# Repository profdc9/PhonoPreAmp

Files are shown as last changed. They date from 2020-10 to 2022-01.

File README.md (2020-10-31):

# Phono Preamplifier

This is a PCB for Bill Christie's phono preamplifier as detailed in his article "Build an External Phonograph Preamplifier" in the 07/13 issue of audioXpress.  The original article can be found at

https://audioxpress.com/article/You-Can-DIY-Build-an-External-Phono-Preamplifier

https://audioxpress.com/assets/upload/files/BillChristieExternalPhonoPreampAXJul2013.pdf

The changes made are as follows.  The LME49740, which is not available anymore, has been replaced with two LM4562 op amps.  22 pF Miller capacitors are placed to stabilize the LM4562 from oscillation.  The signal grounds for the two channels are isolated from the power ground by hum breaker resistors.

This is a two-channel PCB layout for the LM3886-based Super Gain Clone by Bob Cordell.  It can be found in Chapter 27 in his book "Audio Amplifiers."

The PCB is made available under the Creative Commons CC-BY-SA 4.0 license.

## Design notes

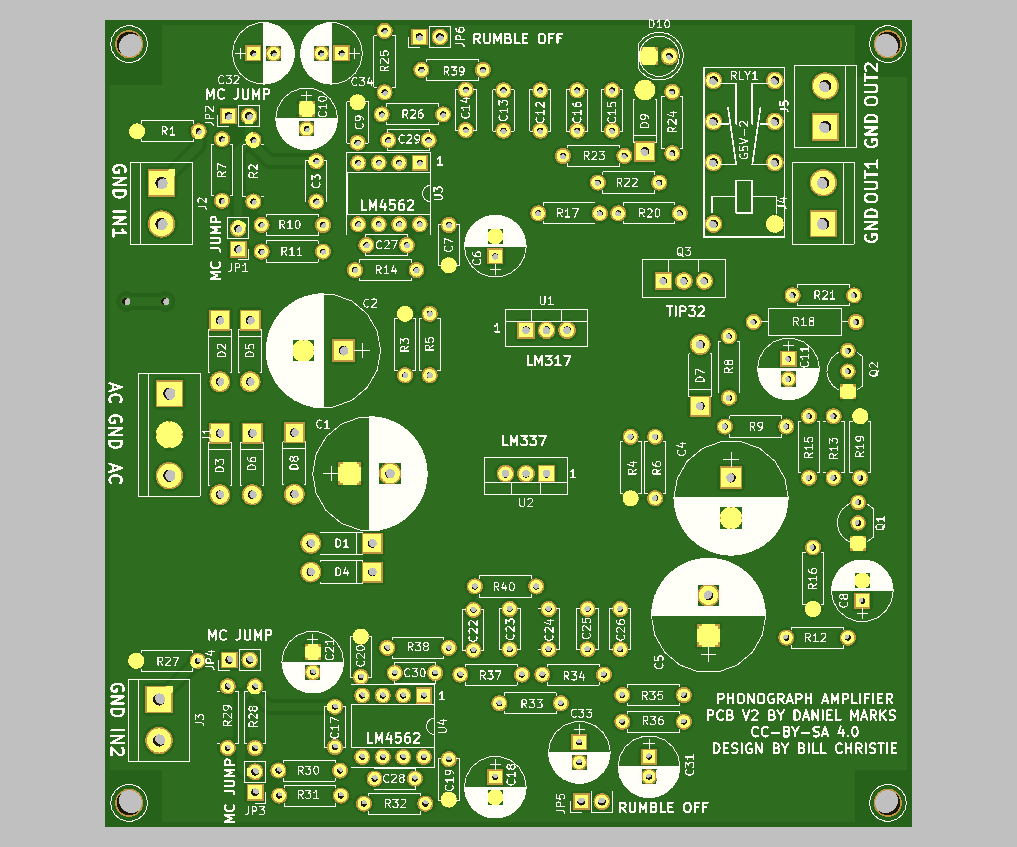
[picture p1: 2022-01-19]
PhonoPreamp.png

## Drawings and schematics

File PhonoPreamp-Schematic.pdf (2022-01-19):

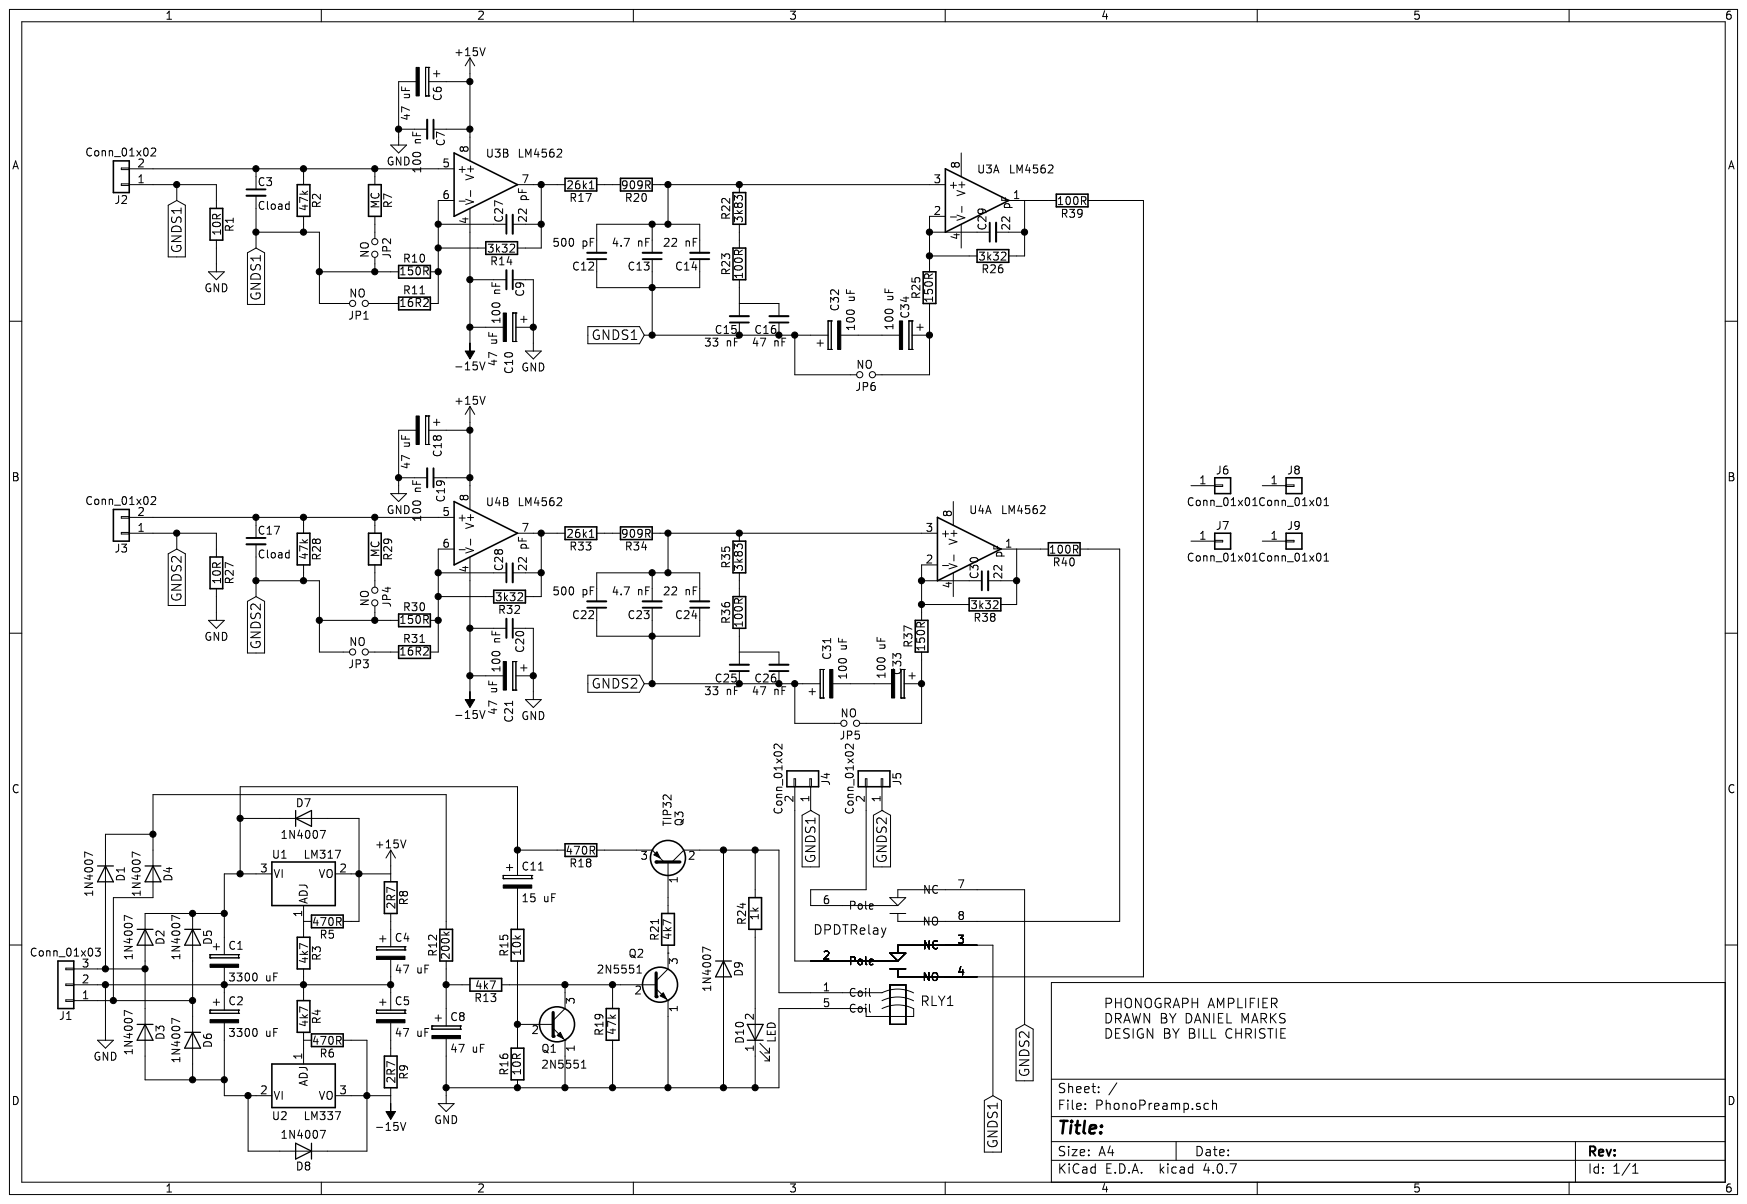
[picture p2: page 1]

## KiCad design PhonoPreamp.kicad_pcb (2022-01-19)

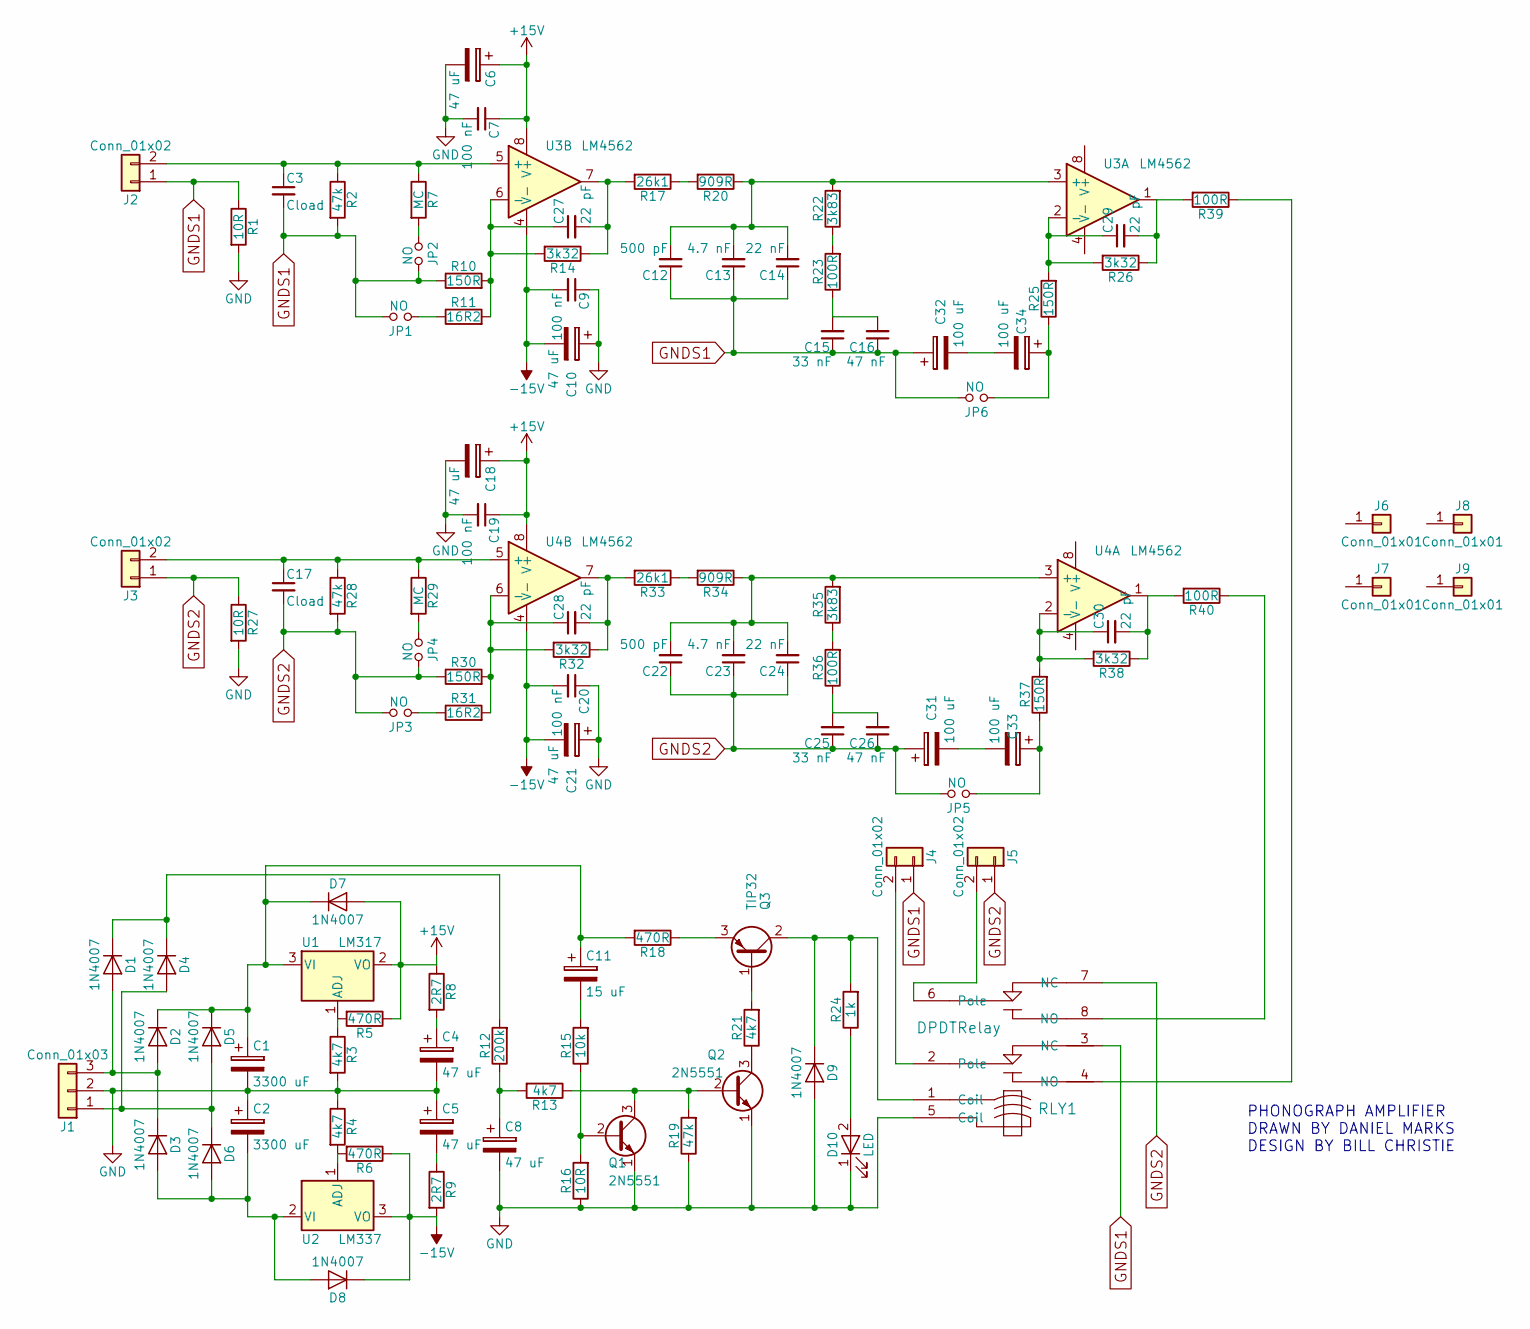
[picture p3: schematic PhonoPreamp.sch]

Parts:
C1, C2: 3300 uF; CP_Radial_D14.0mm_P5.00mm
C3, C17: Cload; C_Disc_D5.0mm_W2.5mm_P5.00mm
C4, C5: 47 uF; CP_Radial_D14.0mm_P5.00mm
C6, C8, C10, C18, C21: 47 uF; CP_Radial_D7.5mm_P2.50mm
C7, C9, C19, C20: 100 nF; C_Disc_D5.0mm_W2.5mm_P5.00mm
C11: 15 uF; CP_Radial_D7.5mm_P2.50mm
C12, C22: 500 pF; C_Disc_D5.0mm_W2.5mm_P5.00mm
C13, C23: 4.7 nF; C_Disc_D5.0mm_W2.5mm_P5.00mm
C14, C24: 22 nF; C_Disc_D5.0mm_W2.5mm_P5.00mm
C15, C25: 33 nF; C_Disc_D5.0mm_W2.5mm_P5.00mm
C16, C26: 47 nF; C_Disc_D5.0mm_W2.5mm_P5.00mm
C27, C28, C29, C30: 22 pF; C_Disc_D5.0mm_W2.5mm_P5.00mm
C31, C32, C33, C34: 100 uF; CP_Radial_D7.5mm_P2.50mm
D1, D2, D3, D4, D5, D6, D7, D8, D9: 1N4007; D_DO-41_SOD81_P7.62mm_Horizontal
D10: LED; LED_D5.0mm
J1: Conn_01x03; TerminalBlock_bornier-3_P5.08mm
J2, J3, J4, J5: Conn_01x02; TerminalBlock_bornier-2_P5.08mm
J6, J7, J8, J9: Conn_01x01; 1pin
JP1, JP2, JP3, JP4, JP5, JP6: NO; Pin_Header_Straight_1x02_Pitch2.54mm
Q1, Q2: 2N5551; TO-92_Inline_Wide
Q3: TIP32; TO-220-3_Vertical
R1, R16, R27: 10R; R_Axial_DIN0207_L6.3mm_D2.5mm_P7.62mm_Horizontal
R2, R19, R28: 47k; R_Axial_DIN0207_L6.3mm_D2.5mm_P7.62mm_Horizontal
R3, R4, R13, R21: 4k7; R_Axial_DIN0207_L6.3mm_D2.5mm_P7.62mm_Horizontal
R5, R6: 470R; R_Axial_DIN0207_L6.3mm_D2.5mm_P7.62mm_Horizontal
R7, R29: MC; R_Axial_DIN0207_L6.3mm_D2.5mm_P7.62mm_Horizontal
R8, R9: 2R7; R_Axial_DIN0207_L6.3mm_D2.5mm_P7.62mm_Horizontal
R10, R25, R30, R37: 150R; R_Axial_DIN0207_L6.3mm_D2.5mm_P7.62mm_Horizontal
R11, R31: 16R2; R_Axial_DIN0207_L6.3mm_D2.5mm_P7.62mm_Horizontal
R12: 200k; R_Axial_DIN0207_L6.3mm_D2.5mm_P7.62mm_Horizontal
R14, R26, R32, R38: 3k32; R_Axial_DIN0207_L6.3mm_D2.5mm_P7.62mm_Horizontal
R15: 10k; R_Axial_DIN0207_L6.3mm_D2.5mm_P7.62mm_Horizontal
R17, R33: 26k1; R_Axial_DIN0207_L6.3mm_D2.5mm_P7.62mm_Horizontal
R18: 470R; R_Axial_DIN0309_L9.0mm_D3.2mm_P12.70mm_Horizontal
R20, R34: 909R; R_Axial_DIN0207_L6.3mm_D2.5mm_P7.62mm_Horizontal
R22, R35: 3k83; R_Axial_DIN0207_L6.3mm_D2.5mm_P7.62mm_Horizontal
R23, R36, R39, R40: 100R; R_Axial_DIN0207_L6.3mm_D2.5mm_P7.62mm_Horizontal
R24: 1k; R_Axial_DIN0207_L6.3mm_D2.5mm_P7.62mm_Horizontal
RLY1: DPDTRelay; G2VRelay
U1: LM317; TO-220-3_Vertical
U2: LM337; TO-220-3_Vertical
U3, U4: LM4562; DIP-8_W7.62mm_Socket

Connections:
+15V: C6.1, C7.1, C18.1, C19.1, D7.2 (A), R5.1, R8.1, U1.2 (VO), U3.8 (V+), U4.8 (V+)
-15V: C9.2, C10.2, C20.2, C21.2, D8.1 (K), R6.1, R9.2, U2.3 (VO), U3.4 (V-), U4.4 (V-)
GND: C1.2, C2.1, C4.2, C5.1, C6.2, C7.2, C8.2, C9.1, C10.1, C18.2, C19.2, C20.1, C21.1, D9.2 (A), D10.1 (K), J1.2, Q1.1 (E), Q2.1 (E), R1.2, R3.2, R4.1, R16.1, R19.1, R27.2, RLY1.5 (Coil)
GNDS1: C3.2, C12.1, C13.1, C14.1, C15.1, C16.1, C32.1, J2.1, J4.1, JP1.2, JP2.2, JP6.2, R1.1, R2.2, R10.1, RLY1.3 (NC)
GNDS2: C17.2, C22.1, C23.1, C24.1, C25.1, C26.1, C31.1, J3.1, J5.1, JP3.2, JP4.2, JP5.2, R27.1, R28.2, R30.1, RLY1.7 (NC)
unnamed: C1.1, C11.1, D2.1 (K), D5.1 (K), D7.1 (K), R18.2, U1.3 (VI)
unnamed: C2.2, D3.2 (A), D6.2 (A), D8.2 (A), U2.2 (VI)
unnamed: C3.1, J2.2, R2.1, R7.1, U3.5 (+)
unnamed: C4.1, R8.2
unnamed: C5.2, R9.1
unnamed: C8.1, R12.1, R13.2
unnamed: C11.2, R15.2
unnamed: C12.2, C13.2, C14.2, R20.1, R22.2, U3.3 (+)
unnamed: C15.2, C16.2, R23.1
unnamed: C17.1, J3.2, R28.1, R29.1, U4.5 (+)
unnamed: C22.2, C23.2, C24.2, R34.1, R35.2, U4.3 (+)
unnamed: C25.2, C26.2, R36.1
unnamed: C27.1, R10.2, R11.2, R14.2, U3.6 (-)
unnamed: C27.2, R14.1, R17.2, U3.7
unnamed: C28.1, R30.2, R31.2, R32.2, U4.6 (-)
unnamed: C28.2, R32.1, R33.2, U4.7
unnamed: C29.1, R25.2, R26.2, U3.2 (-)
unnamed: C29.2, R26.1, R39.2, U3.1
unnamed: C30.1, R37.2, R38.2, U4.2 (-)
unnamed: C30.2, R38.1, R40.2, U4.1
unnamed: C31.2, C33.2
unnamed: C32.2, C34.2
unnamed: C33.1, JP5.1, R37.1
unnamed: C34.1, JP6.1, R25.1
unnamed: D1.1 (K), D4.1 (K), R12.2
unnamed: D1.2 (A), D2.2 (A), D3.1 (K), J1.3
unnamed: D4.2 (A), D5.2 (A), D6.1 (K), J1.1
unnamed: D9.1 (K), Q3.2 (C), R24.2, RLY1.1 (Coil)
unnamed: D10.2 (A), R24.1
unnamed: J4.2, RLY1.2 (Pole)
unnamed: J5.2, RLY1.6 (Pole)
unnamed: JP1.1, R11.1
unnamed: JP2.1, R7.2
unnamed: JP3.1, R31.1
unnamed: JP4.1, R29.2
unnamed: Q1.2 (B), R15.1, R16.2
unnamed: Q1.3 (C), Q2.2 (B), R13.1, R19.2
unnamed: Q2.3 (C), R21.1
unnamed: Q3.1 (B), R21.2
unnamed: Q3.3 (E), R18.1
unnamed: R3.1, R5.2, U1.1 (ADJ)
unnamed: R4.2, R6.2, U2.1 (ADJ)
unnamed: R17.1, R20.2
unnamed: R22.1, R23.2
unnamed: R33.1, R34.2
unnamed: R35.1, R36.2
unnamed: R39.1, RLY1.4 (NO)
unnamed: R40.1, RLY1.8 (NO)

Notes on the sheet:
PHONOGRAPH AMPLIFIER DRAWN BY DANIEL MARKS DESIGN BY BILL CHRISTIE

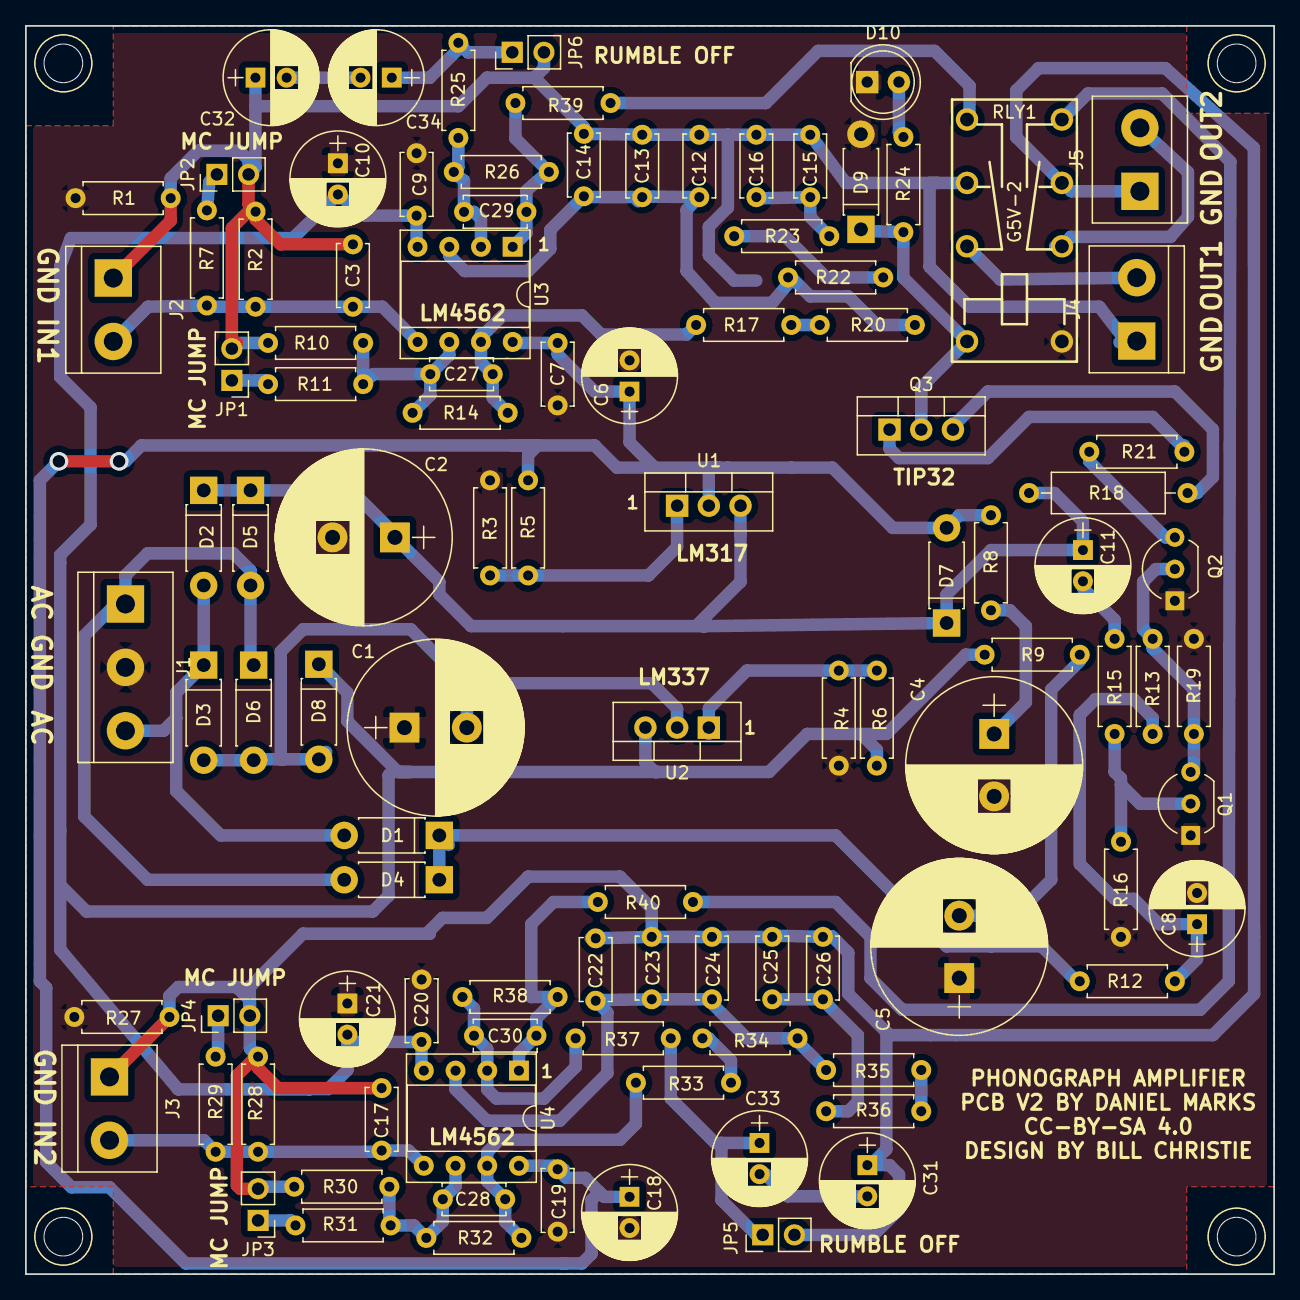
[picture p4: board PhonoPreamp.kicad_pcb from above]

Board: 2 copper layers, 100.0 x 100.0 mm, 107 parts (0 on the bottom side), 53 nets.

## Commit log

2020-11-19 Made some space around capacitors
    [PhonoPreamp-B.Cu.gbr, PhonoPreamp-B.Mask.gbr, PhonoPreamp-B.SilkS.gbr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]
2021-05-28 Bigger capacitor footprints
    [PhonoPreamp-B.Cu.gbr, PhonoPreamp-B.Mask.gbr, PhonoPreamp-B.SilkS.gbr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]
2022-01-19 Added rumble filter
    [PhonoPreamp-B.Cu.gbr, PhonoPreamp-B.Mask.gbr, PhonoPreamp-B.SilkS.gbr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]
